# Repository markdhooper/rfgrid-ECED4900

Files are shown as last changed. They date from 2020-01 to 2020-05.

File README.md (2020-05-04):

# rfgrid - An Interactive RFID Display
Our (Mark Hooper & Burack Ozter) Senior Year Project as part of the Dalhousie Bachelor of Electrical Engineering Program.

Modular arrays of RFID readers are embedded beneath a projection surface upon which a short-throw projector displays contextual visual and audio feedback based on the application running on a host machine. 

<p align="center">
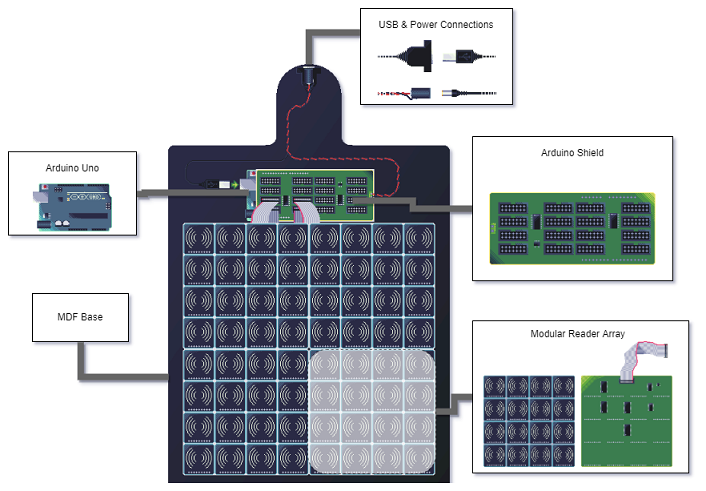
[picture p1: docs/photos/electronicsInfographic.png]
  
</p>
<p align="center">
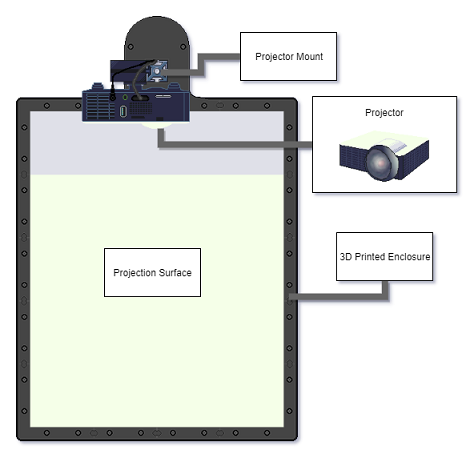
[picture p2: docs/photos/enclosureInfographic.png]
  
</p>

<p align="center">
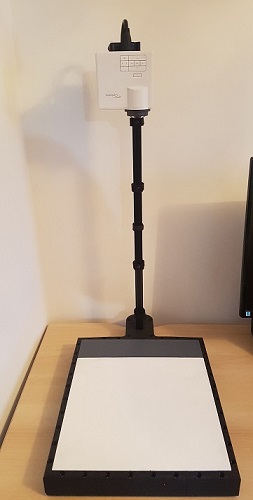
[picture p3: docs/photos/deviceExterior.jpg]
  
</p>
<p align="center">
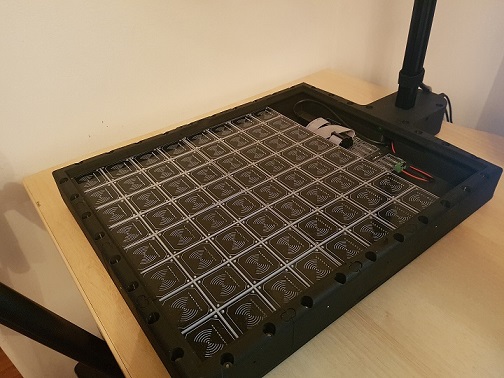
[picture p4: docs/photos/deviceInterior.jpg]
  
</p>

## Application Demonstrations
RFGRID - RPG (http://www.youtube.com/watch?v=AkpBl5bfDys)
RFGRID - SEQUENCER (http://www.youtube.com/watch?v=AWikCM2gaQc)
RFGRID - CHESS (http://www.youtube.com/watch?v=Hl0dvJiLpyY)

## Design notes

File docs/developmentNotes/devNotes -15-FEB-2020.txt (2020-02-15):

There is an issue when loading my rpg(non-communicating) game. 

I fixed the launch by renaming rfgridNOCOMM.py to rpg(non-communicating).py
I also had to comment out the include statement for the rfgridCommunication module as it was throwing because I didn't have the 
serial.tools included or something..

Also: 

I can't modify the background, or the grid on a game that already exists because it's looking for /application/8x8. This 
is a bug in where the directory is. My problem was that the config file was messed up for my game. So I ended up having to
run the calibration tool using the python script instead of the .exe. That seemed to get it working. 

Anyway, just thought i'd document this here.

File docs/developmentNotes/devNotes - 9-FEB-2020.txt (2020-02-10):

[folders]
<whatever the user named their game>

Directory Structure Requirements:
	[<gameName>]
	->[configs]
	....->grid.rfgrid          (created by running rfgridDispCalib.py)
	....->default.rfgridbg	   (created by running rfgridBackgroundCalib.py *user has to pick a background image,and it needs to be renamed and copied first!)
	....->tags.rfgridtag       (created using the C# application)
	->[fonts]
	....->__init__.py
	....->UbuntuMono-Regular.ttf
	->[images]
	....->[backgrounds]
	........->__init__.py
	........-> (the background selected by the user is copied here and renamed default.jpg)
	....->[objects]
	........->__init__.py
	........-> (whatever images selected by the user for tags are copied here)
	->[sounds]
	....-> (whatever sounds selected by the user are copied here)
	->__init__.py
	->ptext.py
	-><gameName>.py (This will be a re-named copy of rfgridGame.py (which is a modified version of the current rfgridAppTest.py))
	->rfgrid.py
	->rfgridBackgroundCalib.py
	->rfgridDispCalib.py
	->rfgridCommunications.py (I need to make this)
	->rfgridDispCalib.py

shit I need to do:
	make rfgridCommunications.py
	make rfgridGame.py (which uses rfgridCommunications.py to talk to the arduino)
	change how rfgridBackgroundCalib.py creates and stores background data (should be based on number of squares)
	change how rfgrid.py loads background information (should resize based on number of squares in default.rfgridbg)
	change the default ptext font to UbuntoMono-Regular.ttf

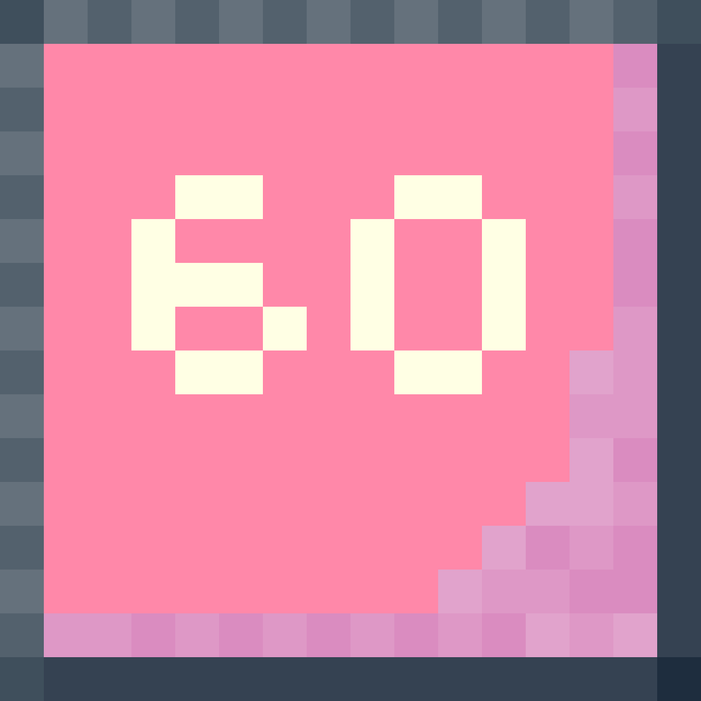
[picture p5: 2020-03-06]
applications/sequencer/images/objects/bpm60.png

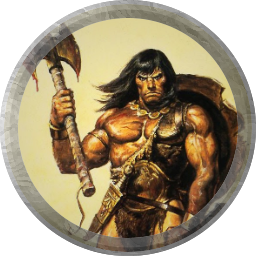
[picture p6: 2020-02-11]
applications/rpg_non_communicating/images/objects/barbarian.png

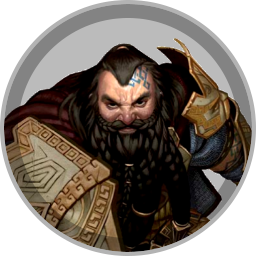
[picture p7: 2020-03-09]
applications/RPG/images/objects/dwarf.png

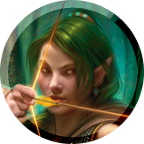
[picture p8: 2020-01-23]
applications/rpg_non_communicating/images/objects/archer.png

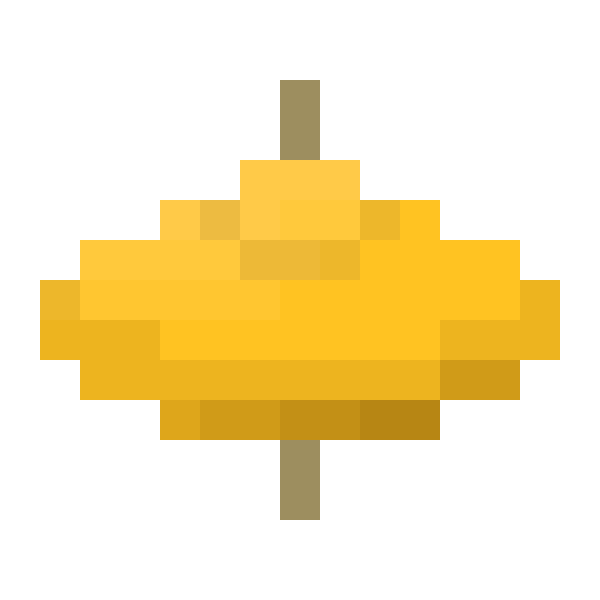
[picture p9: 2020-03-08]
applications/sequencer/images/objects/chh2.png

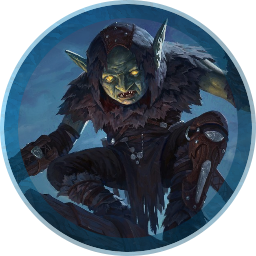
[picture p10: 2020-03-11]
applications/RPG/images/objects/e4.png

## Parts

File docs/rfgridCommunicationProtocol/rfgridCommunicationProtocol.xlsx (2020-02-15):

RFGRID - Communication Protocol
Argument Size Reference
1 Byte | 2 Bytes |  | 4 Bytes |  |  |  | Variable
H/L | H | L | HH | HL | LH | LL | MSB | … | LSB
Host - Data Transmission Format
Name | Type | CMD | Arguments/Data
UPDATE | Acknowledge | 0xF0 | ID | X | Y
GETID | Request | 0xF1 | X | Y
GETXY | Request | 0xF2 | ID
BLOCK | Request | 0xF3 | ID | ARG
READ_ID | Request | 0xF4 | ID | OFFSET | SIZE
WRITE_ID | Request | 0xF5 | ID | OFFSET | SIZE | DATA
READ_XY | Request | 0xF6 | X | Y | OFFSET | SIZE
SYNC | Request | 0xFF | START/STOP | XMAX | YMAX
Device - Data Transmission Format
Name | Type | CMD | Arguments/Data
UPDATE | Event | 0x00 | ID | X | Y
GETID | Response | 0x01 | ID | X | Y
GETXY | Response | 0x02 | ID | X | Y
BLOCK | Response | 0x03 | ID | ARG
READ_ID | Response | 0x04 | ID | OFFSET | SIZE | DATA
WRITE_ID | Response | 0x05 | ID | OFFSET | SIZE
READ_XY | Response | 0x06 | ID | X | Y | OFFSET | SIZE | DATA
SYNC | Response | 0x0F | START/STOP | XMAX | YMAX

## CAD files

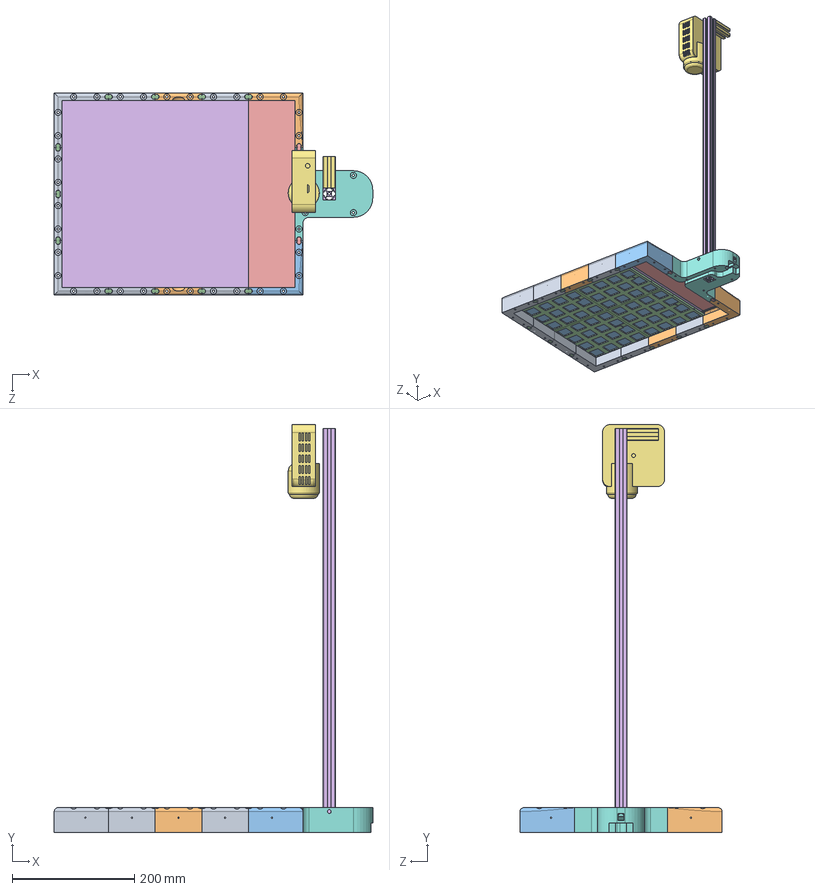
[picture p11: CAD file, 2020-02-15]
docs/cadModels/SolidWorks/rfgrid_assembly.SLDASM
520.7 x 666.8 x 330.2 mm
corner_a x 2
corner_b_l
corner_b_r
dovetail_key x 11
dovetail_key_flat x 2
extruded_aluminium_a
extruded_aluminium_b
projector_mount_base
side x 6
side_notch x 2
reader x 64
reader_tray x 4
menu_surface
projection_surface
projector

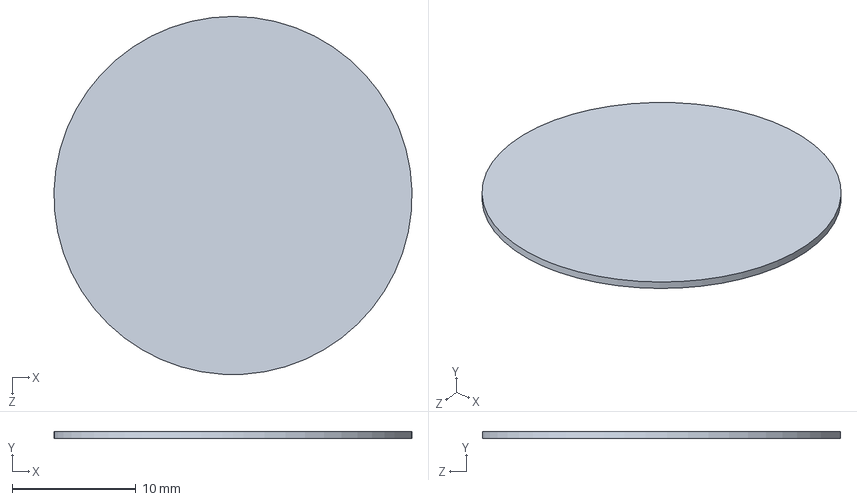
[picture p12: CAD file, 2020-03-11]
docs/cadModels/SolidWorks/cubeSpacer.SLDPRT
29.0 x 0.6 x 29.0 mm

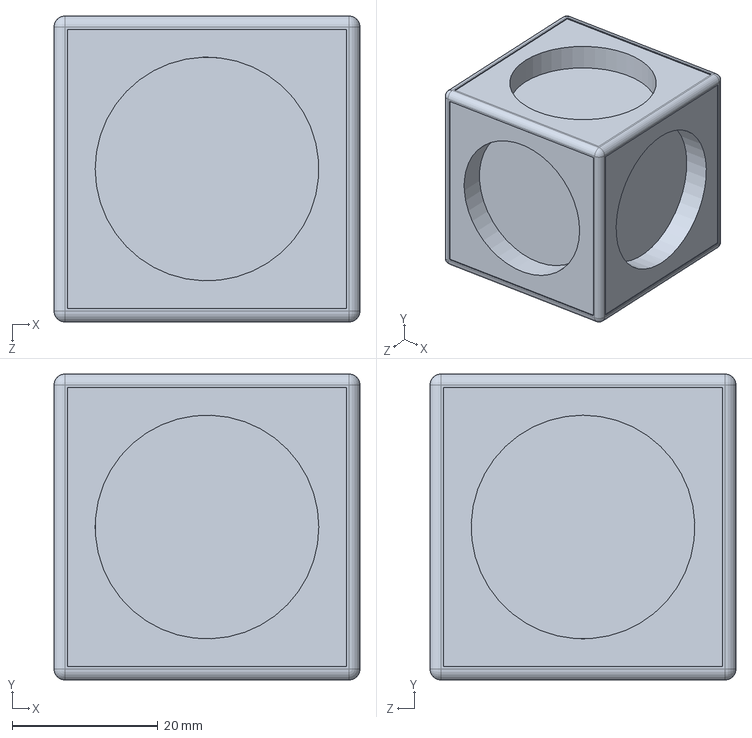
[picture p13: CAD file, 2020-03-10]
docs/cadModels/SolidWorks/tag_cube.SLDPRT
42.0 x 42.0 x 42.0 mm

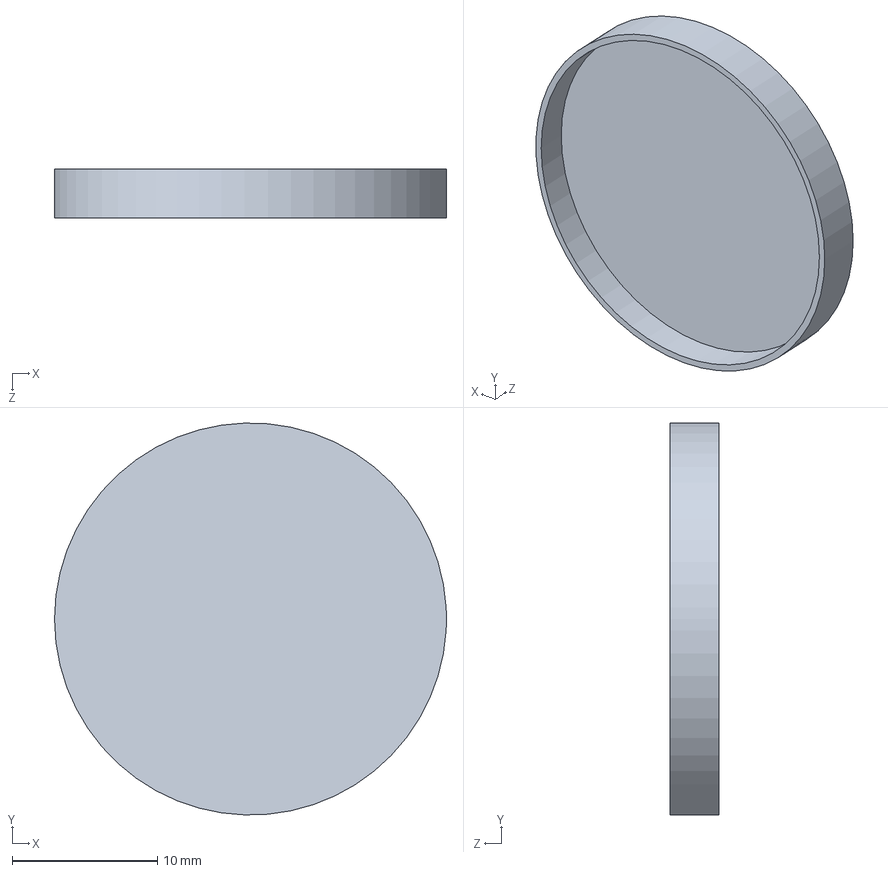
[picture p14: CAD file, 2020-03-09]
docs/cadModels/SolidWorks/rfid_tag_cover_v2(b).SLDPRT
27.0 x 27.0 x 3.40 mm

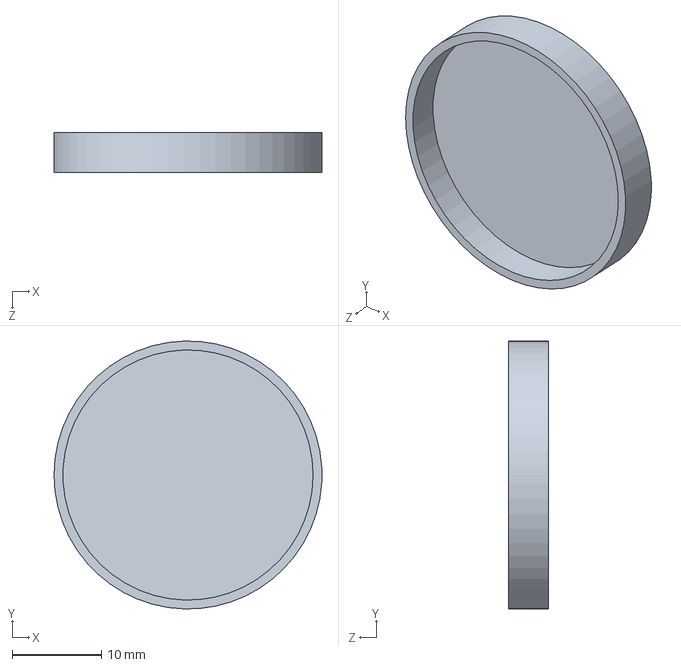
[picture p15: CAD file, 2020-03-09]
docs/cadModels/SolidWorks/rfid_tag_cover_v2(a).SLDPRT
30.0 x 30.0 x 4.50 mm

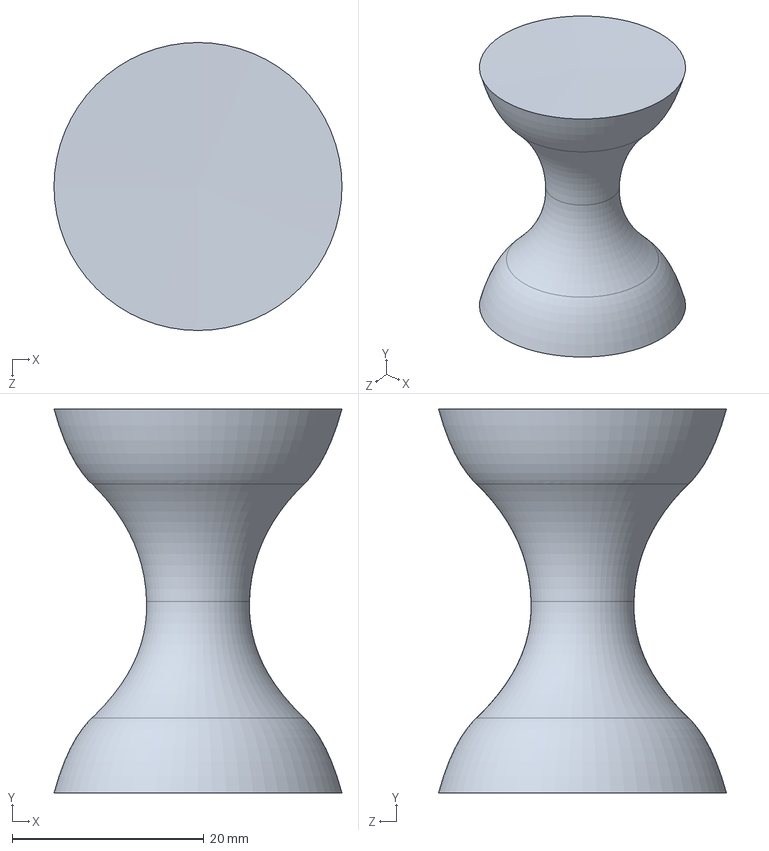
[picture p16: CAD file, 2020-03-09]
docs/cadModels/SolidWorks/turn_timer.SLDPRT
30.0 x 40.0 x 30.0 mm

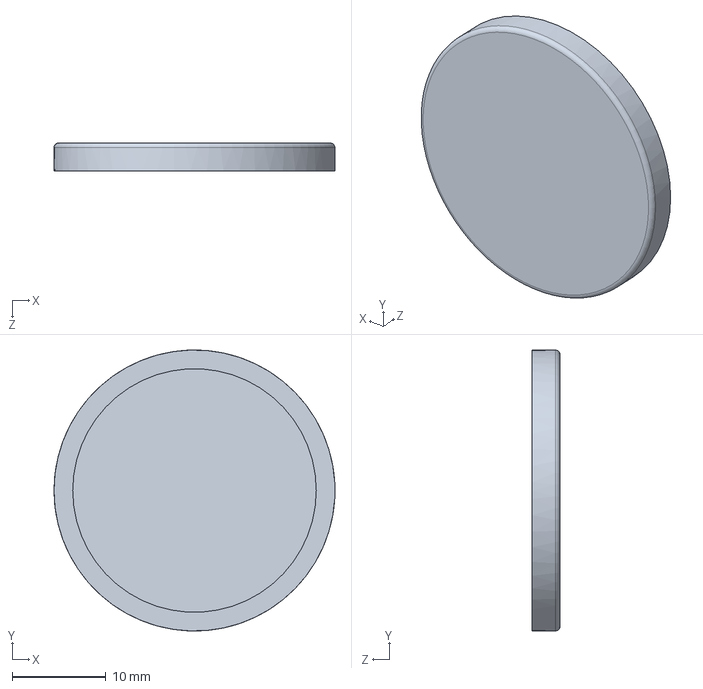
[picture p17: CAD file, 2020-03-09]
docs/cadModels/SolidWorks/rfid_tag_cover.SLDPRT
30.0 x 30.0 x 3.00 mm

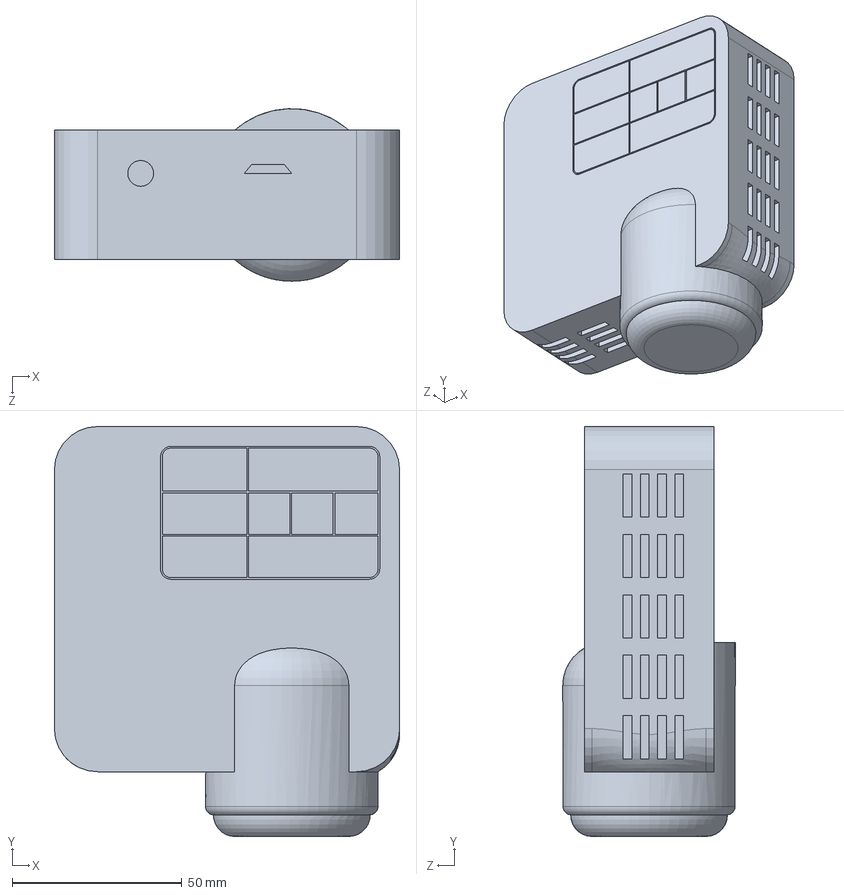
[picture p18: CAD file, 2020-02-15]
docs/cadModels/SolidWorks/projector.SLDPRT
101.6 x 120.6 x 50.8 mm

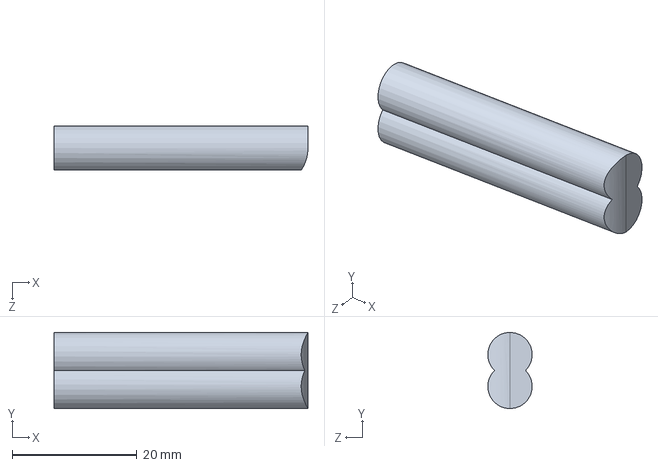
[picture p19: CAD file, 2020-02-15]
docs/cadModels/SolidWorks/dovetail_key.SLDPRT
40.6 x 12.2 x 7.10 mm

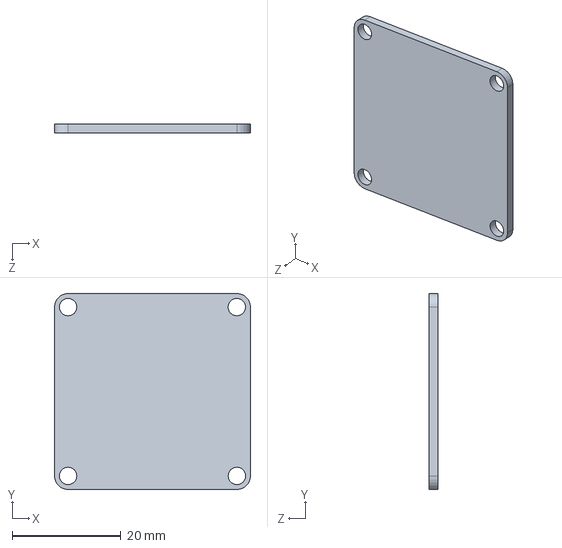
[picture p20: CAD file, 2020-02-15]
docs/cadModels/SolidWorks/reader.SLDPRT
36.0 x 36.0 x 1.60 mm

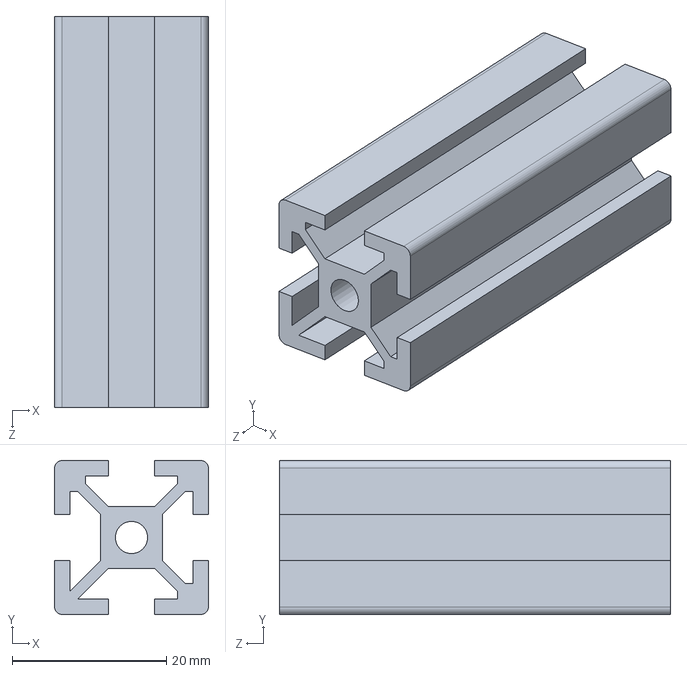
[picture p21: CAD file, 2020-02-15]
docs/cadModels/SolidWorks/extruded_aluminium_b.SLDPRT
20.0 x 20.0 x 50.8 mm

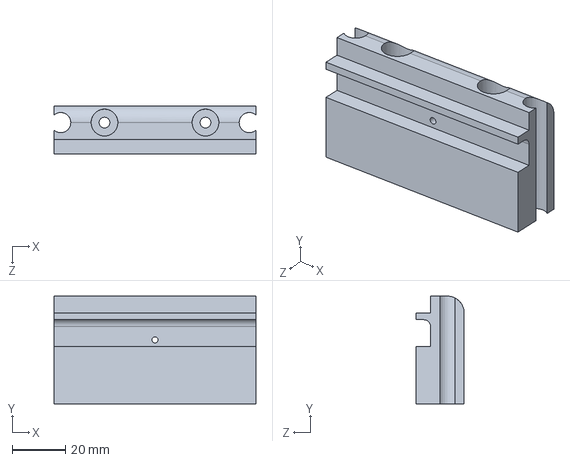
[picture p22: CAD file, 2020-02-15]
docs/cadModels/SolidWorks/side.SLDPRT
76.2 x 40.6 x 18.3 mm

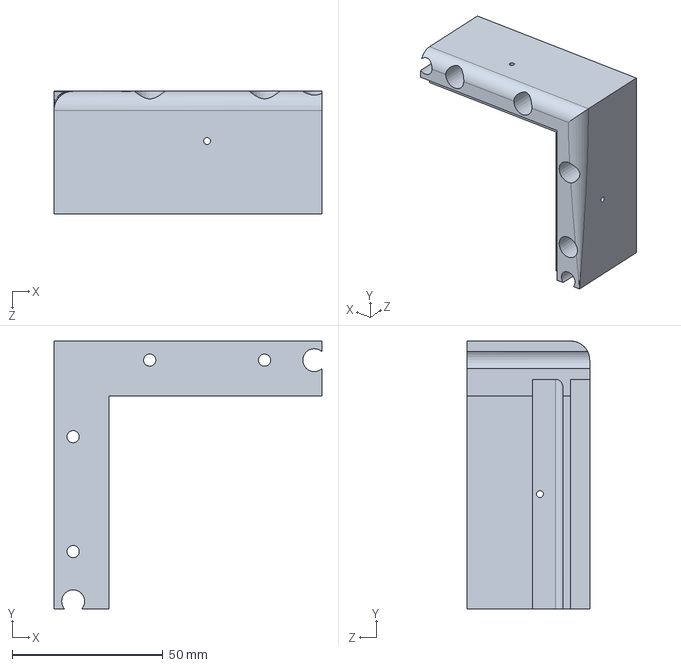
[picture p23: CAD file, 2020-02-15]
docs/cadModels/SolidWorks/corner_b_l.SLDPRT
88.9 x 88.9 x 40.6 mm

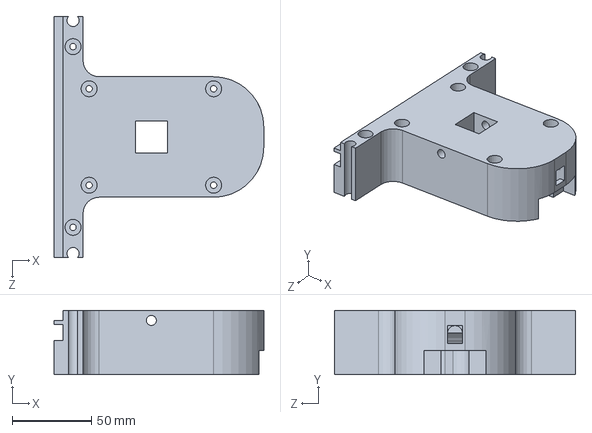
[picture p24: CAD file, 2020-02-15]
docs/cadModels/SolidWorks/projector_mount_base.SLDPRT
132.6 x 40.6 x 152.4 mm

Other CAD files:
docs/cadModels/SolidWorks/dovetail_key_flat.SLDPRT
docs/cadModels/SolidWorks/corner_b_r.SLDPRT
docs/cadModels/SolidWorks/corner_a.SLDPRT
docs/cadModels/SolidWorks/projection_surface.SLDPRT
docs/cadModels/SolidWorks/extruded_aluminium_a.SLDPRT
docs/cadModels/SolidWorks/menu_surface.SLDPRT
docs/cadModels/SolidWorks/nut_driver.SLDPRT
docs/cadModels/SolidWorks/reader_tray.SLDPRT
docs/cadModels/SolidWorks/side_notch.SLDPRT
docs/cadModels/SolidWorks/t_nut.SLDPRT
docs/cadModels/stl/corner_a.STL
docs/cadModels/stl/corner_b_l.STL
docs/cadModels/stl/corner_b_r.STL
docs/cadModels/stl/cubeSpacer.STL
docs/cadModels/stl/dovetail_key.STL
docs/cadModels/stl/dovetail_key_flat.STL
docs/cadModels/stl/nut_driver.STL
docs/cadModels/stl/projector_mount_base.STL
docs/cadModels/stl/rfid_tag_cover.STL
docs/cadModels/stl/rfid_tag_cover_v2(a).STL
docs/cadModels/stl/rfid_tag_cover_v2(b).STL
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

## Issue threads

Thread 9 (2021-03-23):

Model of board for MFRC522

dannygrob, 2021-03-23:
Hi!

Really cool project you guys made. I'm looking into making a grid of rfid readers. I can't seem to find the square MFRC522 module that you are using, can you tell me where you got those?

Are the schematics also available in gerber btw? I have no issues designing my own pcb, but having a good reference helps!

Danny

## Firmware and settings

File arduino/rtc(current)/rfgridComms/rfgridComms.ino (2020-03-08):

/*****************************************************************************/
/* Program Name:  rfgrid.ino  (https://github.com/markdhooper/rfgridECED4900)*/
/* Programmer:    Mark Hooper (https://github.com/markdhooper)               */
/* Description:   This program is intended for use with an Arduino UNO       */
/*                microcontroller connected via usb to a host machine        */
/*                running a python script at the repository linked above.    */
/*                You will also require an rfgridShield and at least one     */
/*                rfgrid modular array unit. For more information, please    */
/*                see the github repo linked above.                          */
/* Behavior:      This sketch will determine how many readers are connected. */
/*                and will inform the host machine when it detects an rfid   */
/*                tag. The current protocol is only 1-way at present.        */
/*****************************************************************************/

#include <SPI.h>
#include <MFRC522.h> //https://github.com/miguelbalboa/rfid

/*****************************************************************************/
/* Constants */
/*****************************************************************************/

/* Pin Assignments */
#define S0_PIN 2    
#define S1_PIN 3    
#define S2_PIN 4    
#define S3_PIN 5    
#define S4_PIN 6    
#define S5_PIN 7    
#define S6_PIN 8    
#define S7_PIN 9    
#define SDA_PIN 10  
#define SCK_PIN 13  
#define MOSI_PIN 11 
#define MISO_PIN 12 
#define RST_PIN 14  
#define NOT_EN_PIN 6

/* Additional Constants */
#define UPDATE_MSG_SZ 7
#define TRIAL_THRESHOLD 1
#define READER_LIMIT 256
#define BANK_MAX 16
#define READER_MAX 16
#define BLOCKED_TAG_MAX 16
#define BOARD_CONFIG4x4   0b0000000000000001
#define BOARD_CONFIG8x8   0b0000000000110011
#define BOARD_CONFIG12x12 0b0000011101110111
#define BOARD_CONFIG16x16 0b1111111111111111

/*****************************************************************************/
/* Data Structures */
/*****************************************************************************/
union readerLocation {
    uint8_t addr8;
    struct BR
	{
        uint8_t readerID : 4;
        uint8_t bankID : 4;
    }addr4;
    struct ydxdymxm
	{
        uint8_t xmod : 2;
        uint8_t ymod : 2;
        uint8_t xdiv : 2;
        uint8_t ydiv : 2;
    }xy;
  struct ab
  {
    uint8_t ar0 : 1;
    uint8_t ar1 : 1;
    uint8_t ar2 : 1;
    uint8_t ar3 : 1;
    uint8_t ab0 : 1;
    uint8_t ab1 : 1;
    uint8_t ab2 : 1;
    uint8_t ab3 : 1;
  }addrBit;
};

union intUID 
{
  byte uidArr[4];
  uint32_t UID;
};

struct flg
{
	uint8_t ACK : 1;
	uint8_t BLOCK : 1;
	uint8_t reserved : 6;
};


struct Tile
{
  uint32_t UID;
  struct flg FLAGS;
};



/*****************************************************************************/
/* Communication Protocol Defines */
/*****************************************************************************/
#define RX_UPDATE_BYTES 6       //x,y,id
#define RX_GET_ID_BYTES 2       //x,y
#define RX_GET_XY_BYTES 4       //id
#define RX_BLOCK_BYTES 5        //arg, id
#define RX_READ_ID_BYTES 8      //id, offset, size
#define RX_WRITE_ID_BYTES 8     // id, offset, size (DATA)
#define RX_READ_XY_BYTES 6      // x, y, offset, size
#define RX_SYNC_BYTES 3         // begin, xmax, ymax

#define TX_UPDATE_BYTES 7       // CMD, x,y,id
#define TX_GET_ID_BYTES 7       // CMD, x,y,id
#define TX_GET_XY_BYTES 7       // CMD, x,y,id
#define TX_BLOCK_BYTES 6        // CMD, arg, id
#define TX_READ_ID_BYTES 9      // CMD, id, offset, size, (DATA)
#define TX_WRITE_ID_BYTES 9     // CMD, id, offset, size
#define TX_READ_XY_BYTES 11      // CMD, x, y, id, offset, size (DATA)
#define TX_SYNC_BYTES 4         // CMD, begin, x_max, y_max

/*****************************************************************************/
/* Global Variables */
/*****************************************************************************/
union intUID objID;
struct Tile Tiles[READER_LIMIT];
MFRC522 Reader(SDA_PIN, RST_PIN);
int ReaderCount = 0;
uint16_t boardMask = 0xFFFF;
uint8_t boardSequence[16] = {0,0,0,0,0,0,0,0,0,0,0,0,0,0,0,0};
uint8_t boardSeqLen = 0;
uint32_t blockedTags[BLOCKED_TAG_MAX];
int BLOCKS_IN_EFFECT = 0;
bool SYNC = 0;
uint8_t x_max_global = 0;
uint8_t y_max_global = 0;


/*****************************************************************************/
/* These automatically get called based on the CMD byte read in the loop()   */
/*****************************************************************************/
void RX_UPDATE()
{
	uint8_t x, y;
	intUID rx_id;
	
	byte argBytes[RX_UPDATE_BYTES];
	Serial.readBytes(argBytes,RX_UPDATE_BYTES);
	
	x = argBytes[4]; 
	y = argBytes[5]; 
	rx_id.uidArr[0] = argBytes[3];
	rx_id.uidArr[1] = argBytes[2]; 
	rx_id.uidArr[2] = argBytes[1]; 
	rx_id.uidArr[3] = argBytes[0]; 
	
	//host has acknowledged an update sent by the device
	//clear the ACK flag for the corresponding reader
	uint8_t addr;
	XYToAddr(x,y,addr);
	if(Tiles[addr].UID == rx_id.UID)
	{
		Tiles[addr].FLAGS.ACK = 0;
	}

}

void RX_GET_ID()
{
	uint8_t x, y;
	uint32_t id;
	
	byte argBytes[RX_GET_ID_BYTES];
	Serial.readBytes(argBytes,RX_GET_ID_BYTES);
	
	x = argBytes[0];
	y = argBytes[1];
	
	uint8_t addr;
	XYToAddr(x,y,addr);
	id = Tiles[addr].UID;
	
	//transmit the result
	TX_GET_ID(id, x, y);
  
}

void RX_GET_XY()
{
	uint8_t x = 255; 
	uint8_t y = 255;
	intUID id;
	
	byte argBytes[RX_GET_XY_BYTES];
	Serial.readBytes(argBytes,RX_UPDATE_BYTES);
	
	id.uidArr[0] = argBytes[3];
	id.uidArr[1] = argBytes[2];
	id.uidArr[2] = argBytes[1];
	id.uidArr[3] = argBytes[0];
       
	union readerLocation addr;
	for(int i = 0; i < boardSeqLen; i++)
	{
		addr.addr4.bankID = boardSequence[i];
		for(int j = 0; j < 16; j++)
		{
			addr.addr4.readerID = (uint8_t)j;
			
			if(Tiles[addr.addr8].UID == id.UID)
			{
				addrToXY(addr.addr8,x,y);
			}
		}
	}
	
	//transmit the result
	TX_GET_XY(id.UID,x,y);
}

void RX_BLOCK()
{
	uint8_t arg;
	intUID id;
  
	byte argBytes[RX_BLOCK_BYTES];
	Serial.readBytes(argBytes,RX_BLOCK_BYTES);  

    id.uidArr[0] = argBytes[3];
    id.uidArr[1] = argBytes[2];
    id.uidArr[2] = argBytes[1];
    id.uidArr[3] = argBytes[0];
    arg = argBytes[4];

  if(id.UID == 0){
    arg = 0;
    TX_BLOCK(id.UID,arg);
    return;
  }
  
  if(arg)
  {
	  //host wants us to block updates from this UID
	  for(int i = 0; i < BLOCKED_TAG_MAX; i++)
	  {
		  if(!blockedTags[i])
		  {
			  //we found a free slot, store the ID of the tag to block
			  blockedTags[i] = id.UID;
			  BLOCKS_IN_EFFECT++;
        for(int j = 0; j< READER_LIMIT; j++)
        {
          if(Tiles[j].UID == id.UID)
          {
            Tiles[j].FLAGS.BLOCK = 1;
            Tiles[j].FLAGS.ACK = 0;
            break;  
          }
        }
        break;
		  }
		  else if(i == BLOCKED_TAG_MAX -1)
		  {
			  //We can't block this tag until they unblock another one
			  arg = 0;
		  }
	  }
  }
  else
  {
	  //they want to unblock a tag
	  for(int i = 0; i < BLOCKED_TAG_MAX; i++)
	  {
		  if(blockedTags[i] == id.UID)
		  {
			  //we found a match
			  blockedTags[i] = 0;
			  BLOCKS_IN_EFFECT--;
        //Search for a reader with an id that matches our blocked tag
        // and clear the flag
        for(int j = 0; j< READER_LIMIT; j++)
        {
          if(Tiles[j].UID == id.UID)
          {
            //we found a match, unblock 
            //the reader. And ensure that
            //it tells the host where the
            //newely unblocked tag is.
            Tiles[j].FLAGS.BLOCK = 0;
            Tiles[j].FLAGS.ACK = 1;
            break;  
          }
        }
        break;
		  }
	  }
  }

  //transmit the result
  TX_BLOCK(id.UID,arg);
}

void RX_READ_ID()
{
  intUID id;
  uint16_t ofs;
  uint16_t sz;
  byte data[16];    //FIXED SIZES WILL BE NEEDED, WE CAN PICK A MAXIMUM (FOR NOW) OF 16
  
  byte argBytes[RX_READ_ID_BYTES];
  Serial.readBytes(argBytes,RX_UPDATE_BYTES);

  //do the things

  /*****************************************************************************/
  /* HARD CODED - ONLY FOR TESTING, THE REAL VALUES WILL NEED TO BE COMPUTED   */
              id.uidArr[0] = argBytes[3];
              id.uidArr[1] = argBytes[2];
              id.uidArr[2] = argBytes[1];
              id.uidArr[3] = argBytes[0];
              ofs = argBytes[4] + (argBytes[5]<<8);
              sz = 16;  //going with a fixed size for now....
  /*****************************************************************************/

  //transmit the result
  TX_READ_ID(id.UID, ofs, sz, data);
}

void RX_WRITE_ID()
{
  intUID id;
  uint16_t ofs;
  uint16_t sz;
  
  byte argBytes[RX_WRITE_ID_BYTES];
  Serial.readBytes(argBytes,RX_UPDATE_BYTES);

  //do the things

  /*****************************************************************************/
  /* HARD CODED - ONLY FOR TESTING, THE REAL VALUES WILL NEED TO BE COMPUTED   */
              id.uidArr[0] = argBytes[3];
              id.uidArr[1] = argBytes[2];
              id.uidArr[2] = argBytes[1];
              id.uidArr[3] = argBytes[0];
              ofs = argBytes[5] + (argBytes[4]<<8);
              sz = argBytes[7] + (argBytes[6]<<8);
  /*****************************************************************************/

  //transmit the result
  TX_WRITE_ID(id.UID, ofs, sz);
}

void RX_READ_XY()
{
  uint8_t x;
  uint8_t y;
  uint32_t id;
  uint16_t ofs;
  uint16_t sz;
  
  byte argBytes[RX_READ_XY_BYTES];
  Serial.readBytes(argBytes,RX_UPDATE_BYTES);  

  //do the things


  /**********************************************************************/
  /* HARDCODED ONLY FOR TESTING, these values will need to be computed  */
          x = argBytes[0];
          y = argBytes[1];
          id = 0xBEEF;
          ofs = (argBytes[2]<<8) + argBytes[3];
          sz = (argBytes[4]<<8) + argBytes[5];
          byte data[sz];
  /**********************************************************************/
  
  //transmit the result
  TX_READ_XY(x, y, id, ofs, sz, data);
}

void RX_SYNC()
{
	uint8_t arg;
	uint8_t x_max;
	uint8_t y_max;
	
	byte argBytes[RX_SYNC_BYTES];
	Serial.readBytes(argBytes,RX_SYNC_BYTES);
	

	arg = argBytes[0];
  x_max = argBytes[1];
  y_max = argBytes[2];
  
	if(!arg){
		//host wants to stop communicating
		SYNC = false;
	}else if(x_max_global == x_max && y_max_global == y_max){
    SYNC = true;
	}else{
	  arg = 0;
    x_max = x_max_global;
    y_max = y_max_global;
	}
	
	//transmit the result
	TX_SYNC(arg,x_max,y_max);
}


/*****************************************************************************/
/* Call these when you want to transmit a specific response to the Host      */
/*****************************************************************************/

void TX_UPDATE(uint32_t id, uint8_t x, uint8_t y )
{
    intUID temp;
    temp.UID = id;
    uint8_t buf[TX_UPDATE_BYTES];
    buf[0] = 0x00;        //UPDATE COMMAND
    buf[1] = temp.uidArr[3];
    buf[2] = temp.uidArr[2];
    buf[3] = temp.uidArr[1];
    buf[4] = temp.uidArr[0];
    buf[5] =  x;
    buf[6] =  y;
    Serial.write(buf, TX_UPDATE_BYTES);
}

void TX_GET_ID(uint32_t id, uint8_t x, uint8_t y)
{
    intUID temp;
    temp.UID = id;
    uint8_t buf[TX_GET_ID_BYTES];
    buf[0] = 0x01;        //GET_ID COMMAND
    buf[1] = temp.uidArr[3];
    buf[2] = temp.uidArr[2];
    buf[3] = temp.uidArr[1];
    buf[4] = temp.uidArr[0];
    buf[5] =  x;
    buf[6] =  y;
    Serial.write(buf, TX_GET_ID_BYTES);
}

void TX_GET_XY(uint32_t id, uint8_t x, uint8_t y)
{
    intUID temp;
    temp.UID = id;
    uint8_t buf[TX_GET_XY_BYTES];
    buf[0] = 0x02;        //GET_XY COMMAND
    buf[1] = temp.uidArr[3];
    buf[2] = temp.uidArr[2];
    buf[3] = temp.uidArr[1];
    buf[4] = temp.uidArr[0];
    buf[5] =  x;
    buf[6] =  y;
    Serial.write(buf, TX_GET_XY_BYTES);
}

void TX_BLOCK(uint32_t id, uint8_t arg)
{
    intUID temp;
    temp.UID = id;
    uint8_t buf[TX_BLOCK_BYTES];
    buf[0] = 0x03;        //BLOCK COMMAND
    buf[1] = temp.uidArr[3];
    buf[2] = temp.uidArr[2];
    buf[3] = temp.uidArr[1];
    buf[4] = temp.uidArr[0];
    buf[5] =  arg;
    Serial.write(buf, TX_BLOCK_BYTES);
}

void TX_READ_ID(uint32_t id, uint16_t ofs, uint16_t sz, byte* data)
{
    intUID temp;
    temp.UID = id;
    uint8_t buf[TX_READ_ID_BYTES + sz];
    buf[0] = 0x04;        //READ_ID COMMAND
    buf[1] = temp.uidArr[3];
    buf[2] = temp.uidArr[2];
    buf[3] = temp.uidArr[1];
    buf[4] = temp.uidArr[0];
    buf[5] = (ofs & 0xFF00)>>8;
    buf[6] = (ofs & 0x00FF);
    buf[7] = (sz & 0xFF00)>>8;
    buf[8] = (sz & 0x00FF);
    for(int i = 0; i < sz; i++)
    {
      buf[i+8] = *data;
      data++; 
    }
    Serial.write(buf, TX_READ_ID_BYTES + sz);
}

void TX_WRITE_ID(uint32_t id, uint16_t ofs, uint16_t sz)
{
    intUID temp;
    temp.UID = id;
    uint8_t buf[TX_READ_XY_BYTES];
    buf[0] = 0x05;        //WRITE_ID COMMAND
    buf[1] = temp.uidArr[3];
    buf[2] = temp.uidArr[2];
    buf[3] = temp.uidArr[1];
    buf[4] = temp.uidArr[0];
    buf[5] = (ofs & 0xFF00)>>8;
    buf[6] = (ofs & 0x00FF);
    buf[7] = (sz & 0xFF00)>>8;
    buf[8] = (sz & 0x00FF);
    Serial.write(buf, TX_WRITE_ID_BYTES + sz);
}

void TX_READ_XY(uint8_t x, uint8_t y,uint32_t id, uint16_t ofs, uint16_t sz, byte* data)
{
    intUID temp;
    temp.UID = id;
    uint8_t buf[TX_READ_XY_BYTES + sz];
    buf[0] = 0x06;        //READ_XY COMMAND
    buf[1] = x;
    buf[2] = y;
    buf[3] = temp.uidArr[3];
    buf[4] = temp.uidArr[2];
    buf[5] = temp.uidArr[1];
    buf[6] = temp.uidArr[0];
    buf[7] = (ofs & 0xFF00)>>8;
    buf[8] = (ofs & 0x00FF);
    buf[9] = (sz & 0xFF00)>>8;
    buf[10] = (sz & 0x00FF);
    for(int i = 0; i < sz; i++)
    {
      buf[i+10] = *data;
      data++; 
    }
    Serial.write(buf, TX_READ_XY_BYTES + sz);
}

void TX_SYNC(uint8_t arg, uint8_t x_max, uint8_t y_max)
{
  uint8_t buf[TX_SYNC_BYTES] = {0x0F, arg, x_max, y_max};
  Serial.write(buf, TX_SYNC_BYTES);
}


/*****************************************************************************/
/* Lookup table: the CMD is bitwise anded with 0x07 which gives the index of */
/* the function to call                                                      */
/*****************************************************************************/
void (*RX_LUT[])() = 
{
  RX_UPDATE,
  RX_GET_ID,
  RX_GET_XY,
  RX_BLOCK,
  RX_READ_ID,
  RX_WRITE_ID,
  RX_READ_XY,
  RX_SYNC
}; 


/*****************************************************************************/
/* Functions: (SPI communication, and address translation) */
/*****************************************************************************/

/* Output an 8-bit address to the SPI MUX */
void outputAddress(uint8_t addr)
{
  union readerLocation readerAddr;
  readerAddr.addr8 = addr;
  digitalWrite(S0_PIN, readerAddr.addrBit.ar0);
  digitalWrite(S1_PIN, readerAddr.addrBit.ar1);
  digitalWrite(S2_PIN, readerAddr.addrBit.ar2);
  digitalWrite(S3_PIN, readerAddr.addrBit.ar3);
  digitalWrite(S4_PIN, readerAddr.addrBit.ab0);
  digitalWrite(S5_PIN, readerAddr.addrBit.ab1);
  digitalWrite(S6_PIN, readerAddr.addrBit.ab2);
  digitalWrite(S7_PIN, readerAddr.addrBit.ab3);
}

/* Tests if a reader is present at a given address */
bool initReader(uint8_t addr)
{
  bool result;
  outputAddress(addr);
  delay(10);
  Reader.PCD_Init();
  int numTrials = 0;
  int gainTest = 16;
  for(int j = 0; j < TRIAL_THRESHOLD; j++)
  {
    Reader.PCD_SetAntennaGain(gainTest);
    if(Reader.PCD_GetAntennaGain() == gainTest)
	{
      numTrials++;
    }
  }
  Reader.PCD_AntennaOff();  
  return (numTrials == TRIAL_THRESHOLD);
}
/*****************************************************************************/
//                                                                                       DELETE LATER
/*  */
void sendUpdate(uint8_t addr, uint32_t ID)
{
  union intUID tagID;
  tagID.UID = ID;
  uint8_t msg[UPDATE_MSG_SZ];
  msg[0] = 0;
  msg[1] = tagID.uidArr[3];
  msg[2] = tagID.uidArr[2];
  msg[3] = tagID.uidArr[1];
  msg[4] = tagID.uidArr[0];
  addrToXY(addr,msg[5],msg[6]);
  Serial.write(msg,UPDATE_MSG_SZ);
}

/* Translates an x,y coordinate to an address */
int XYToAddr(byte x, byte y, byte &addr)
{
    union readerLocation RL;
    if((x > 15) || (y > 15)) return 1;
    RL.xy.xmod = x % 4;
    RL.xy.ymod = y % 4;
    RL.xy.xdiv = x/4;
    RL.xy.ydiv = y/4;
    addr = RL.addr8;
    return 0;
}

/* Translates an address to an xy coordinate */
int addrToXY(uint8_t addr, uint8_t &x, uint8_t &y)
{
    union readerLocation RL;
    if(addr > 255) return 1;
    RL.addr8 = addr;
    x = (RL.xy.xdiv * 4) + RL.xy.xmod;
    y = (RL.xy.ydiv * 4) + RL.xy.ymod;
    return 0;    
}

/* checks to see if a given UID is blocked */
bool blocked(uint32_t UID){
	for(int i = 0; i < BLOCKED_TAG_MAX; i++)
	{
		if(blockedTags[i] == UID && UID)
		{
			return true;
		}
	}
	return false;
}
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
void loop()
{
	if(Serial.available())
	{
		byte cmd = Serial.read();
		cmd &= 0x07;      //get the proper index for the LUT
		RX_LUT[cmd]();    //Call the appropriate RX function
	}
	else if(SYNC)
	{
	//No messages from host, scan grid for updates.
		union readerLocation currentAddress;
		for(int i = 0; i < boardSeqLen; i++)
		{
			currentAddress.addr4.bankID = boardSequence[i];
			for(int j = 0; j < 16; j++)
			{
				currentAddress.addr4.readerID = (uint8_t)j;
				outputAddress(currentAddress.addr8); 
				delay(10);
				Reader.PCD_AntennaOn();
				Reader.PCD_SetAntennaGain(16);
				if(Reader.PICC_IsNewCardPresent() && Reader.PICC_ReadCardSerial())
				{
					Reader.PCD_AntennaOff();  
					for( int k = 1; k <= 4; k++)
					{
						objID.uidArr[4-k] = Reader.uid.uidByte[k-1];
					}      
					if((objID.UID != Tiles[currentAddress.addr8].UID)||Tiles[currentAddress.addr8].FLAGS.ACK)
					{
						//State change or host has yet to acknowledge previous state change
						Tiles[currentAddress.addr8].UID = objID.UID;
						if(BLOCKS_IN_EFFECT && blocked(Tiles[currentAddress.addr8].UID))
						{
							Tiles[currentAddress.addr8].FLAGS.BLOCK = 1;
						}
						else
						{
							Tiles[currentAddress.addr8].FLAGS.ACK = 0; //set the acknowledge required flag
							sendUpdate(currentAddress.addr8,Tiles[currentAddress.addr8].UID);
						}
					}
				}
				else
				{
          //No tag was detected 
					Reader.PCD_AntennaOff();
					if((Tiles[currentAddress.addr8].UID != 0))
					{
						//State change or host has yet to acknowledge previous state change
						Tiles[currentAddress.addr8].UID = 0;
            
						if(!Tiles[currentAddress.addr8].FLAGS.BLOCK)
						{
							//updates for the tag previously on this reader are not blocked by host
							Tiles[currentAddress.addr8].FLAGS.ACK = 0; //set the acknowledge required flag
							sendUpdate(currentAddress.addr8,Tiles[currentAddress.addr8].UID);
						}
						else
						{
							//updates for the tag previously on this reader were blocked
							Tiles[currentAddress.addr8].FLAGS.BLOCK = 0;
              Tiles[currentAddress.addr8].FLAGS.ACK = 0;
						}
					}
				}
			}
		}
	}
}

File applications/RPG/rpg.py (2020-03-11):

from rfgrid import *
from rfgridCommunication import *
from time import sleep

rfgrid = rfgridInit()
rfgrid.updateMenu("Initializing Grid:\nPlease Wait...",40,(0,0,0),(255,255,255))
rfgridSerial = rfgridCommInit(rfgrid.grid_x_tiles, rfgrid.grid_y_tiles)
done = False
numPlayers = 4
currentPlayer = 0
playerNames = ["Verrona","Udoghast","Lud","Rugren"]
id = 0
x = 0
y = 0

# THESE ARE SPECIFIC TO rpg.py
MUTE = 2302950640
END_TURN = 695941360
EXPLORE = 2311927792
SCROLL_OFF = 963853040 
SCROLL_ON = 2307276272
MENU_COLOR = (200,200,200)


while not done:
	if (rfgridSerial.inWaiting() > 0):
		# there is data in the serial buffer
		# extract the command byte, and the arguments from the buffer
		cmdIdx, args = rx_rfgrid(rfgridSerial)
		if cmdIdx == 7:
			rfgrid.updateMenu("rfgrid - rpg",60,(0,0,0),MENU_COLOR)
		if cmdIdx == 0:
			id, x, y = RX_LUT[RX_LUT_KEYS[cmdIdx]](args,rfgrid)
			
			# Mute all audio 
			if id == MUTE:
				pygame.mixer.fadeout(5000)
				
			# End the current turn and locate 
			elif id == END_TURN:
				if currentPlayer == numPlayers:
					rfgrid.updateMenu("Dungeon Master's Turn",40,(0,0,0),MENU_COLOR)
					currentPlayer = 0
				else:
					# inform the player that it's their turn
					msg = ("%s's Turn:" % (playerNames[currentPlayer]))
					rfgrid.updateMenu(msg,40,(0,0,0),MENU_COLOR)
					# attempt to pan the map to display that character
					rfgrid.moveCameraToTag(currentPlayer)
					currentPlayer += 1
					
			# Enable background scrolling for tags with renderable images
			elif id == SCROLL_ON:
				rfgrid.scroll_enabled = True
				MENU_COLOR = (200,200,200)
				msg = "\n Character Scrolling ENABLED"
				rfgrid.updateMenu(msg,30,(0,0,0),MENU_COLOR)
			
			# Disable background scrolling for tags with renderable images
			elif id == SCROLL_OFF:
				rfgrid.scroll_enabled = False
				MENU_COLOR = (200,100,100)
				msg = "\n Character Scrolling DISABLED"
				rfgrid.updateMenu(msg,30,(255,0,0),MENU_COLOR)
			
			elif id == EXPLORE:
				step_size = 0
				x_dir = 0
				y_dir = 0
				
				# x cases
				if(x == 0):
					step_size = 7
					x_dir = 1
				elif(x == 1):
					step_size = 2
					x_dir = 1
				elif(x == 7):
					step_size = 7
					x_dir = -1
				elif(x == 6):
					step_size = 2
					x_dir = -1
				
				# y cases
				if(y == 0):
					step_size = 7
					y_dir = 1
				elif(y == 1):
					step_size = 2
					y_dir = 1
				elif(y == 7):
					step_size = 7
					y_dir = -1
				elif(y == 6):
					step_size = 2
					y_dir = -1
						
				for i in range(0,step_size):
					rfgrid.scrollBackground(x_dir,y_dir,smooth = True, speed = 20)
		else:
			RX_LUT[RX_LUT_KEYS[cmdIdx]](args,rfgrid)

	for event in pygame.event.get():
		# IF USER CLOSES THE WINDOW
		if event.type == pygame.QUIT:
			done=True
		
		# ESCAPE KEYPRESS
		if event.type == pygame.KEYDOWN and event.key == pygame.K_ESCAPE:
			done=True

		# ARROW KEYPRESSES
		if event.type == pygame.KEYDOWN and event.key == pygame.K_RIGHT:
			rfgrid.scrollBackground(-1,0,smooth = False)
		elif event.type == pygame.KEYDOWN and event.key == pygame.K_LEFT:
			rfgrid.scrollBackground(+1,0,smooth = False)
		elif event.type == pygame.KEYDOWN and event.key == pygame.K_UP:
			rfgrid.scrollBackground(0,+1,smooth = False)
		elif event.type == pygame.KEYDOWN and event.key == pygame.K_DOWN:
			rfgrid.scrollBackground(0,-1, smooth = False)
	
	clock.tick(20)
pygame.quit()

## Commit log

2020-01-10 Mass upload of software for the rfgrid system: I've never attempted to use gitHub in its intended fashion until today. So this is my first attempt at gettings things more organized. There are current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
    arduino:
    Added the most up-to-date version of the arduino sketch that is currently running on the device.
    Note, this is not using a two way protocol, it is simply sending the x,y and ID of tags.
    python:
    rfgridTools:
    There are some tools that I wrote to make development easier and to
    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
    [rfgridConfig.txt]
2020-01-11 Updated the calibration state and program flow to be more concise and readable. Changed the scaling step to use the left click instead of right click.
2020-01-11 Added configuration file output for grid and backgrounds
    [configsc.txt]
2020-01-13 Changed the calibration to two different scripts. Started preliminary work on pygame wrapper (rfgrid.py) Changed some config file formatting to include the x and y tile count from the background imag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
    [configsc.txt]
2020-01-13 Added draw functionality for game objects, updated app to draw random squares to test. also created a new surface on which to draw game objects. started preliminary work on state table corresponding 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
2020-01-17 Made improvements to backgroud scaler. It is less reliant on cursor position now and automatically adjusts the offset into the grid ensuring that any gaps are divided among the top/bottom or left/rig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
2020-01-19 Cathy's Stuff
    Uploading a preliminary tested version of GETID with python and arduino back and forth.
2020-01-21 GetID and GetXY both tested
    [rfgridConfig.txt]
2020-01-23 Added hardware redesign documentation and work done to prepare for meeting with Dr. Hughes. (rfgridAppTest.py)
    [rfgridModuleSpecifications.xlsx]
2020-01-23 Removed the work that I did today on the hardware re-design as it doesn't pertain to this repo anymore.
    [rfgridModuleSpecifications.xlsx]
2020-01-28 Removed un-necessary print statements, extra backgrounds, un-used images and un-necessary background config files.
    Also re-ran the calibration tool and set the resolution back to 1600x900 (it was changed to 1024x768 and
    the background scaling was not working properly for larger images as a result.
    [rfgrid.py]
2020-01-31 Re-configured the backgrounds and grid calibration files for the new hardware configuration. Adjusted the rfgridAppTest.py file to test out the drawing features that I wrote yesterday now that I have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
2020-02-05 Made communication protocol testing applications for both arduino and python.
2020-02-05 Updated the Communication Protocol Testing Suite. Fixed a bug from the TX side for python. Now can transmit raw bytes.
    [rfgridCommProtocol.py, rfgridComms.ino]
2020-02-07 Re-calibrated the display and added updated communication protocol spreadsheet to the docs folder.
    [rfgridCommunicationProtocol.xlsx]
2020-02-08 Created a new arduino sketch (rfgridComms.ino) tested with rfgridCommProtocol.py. Got sync, getxy, getid, update and block working in one sitting. Works with the grid hardware.
    [rfgridConfig.txt]
2020-02-09 Updated the rfgridComms.ino sketch to fix a quirk of block for sending removal information. Also adjusted consecutive SYNC response behavior. Added missing rx block dialogue in the rfgridCommProtocol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
    [rfgridCommProtocol.py, rfgridComms.ino]
2020-02-10 Consolidated directory structure as required for the rfgrid GUI application (Burak). Arduino real time communication is working, communication emulation is working, and implemented rfgridCommunicatio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
    [CORNER(V2).SLDPRT, CORNER(V2).STL, CORNER-PMOUNT-L(V2).SLDPRT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]
2020-02-10 Uploaded PCB Schematics and re-organized documentation folders.
2020-02-15 Added VS Code and BackgroundCalib fixed
    [rfgrid.py, rfgridCommunication.py]
2020-02-15 Re-organized the documentation folder, renamed the files for the CAD models to make more sense. Updated the communication protocol emulator to auto detect the com port for an arduino.
    [CORNER(V2).SLDPRT, CORNER-PMOUNT-L(V2).SLDPRT, CORNER-PMOUNT-R(V2).SLDPRT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]
2020-02-18 Made a (non-communicating) version of chess, and also fixed a sound bug for all rfgrid.py files, we ensure that the number of channels is set to the number of tags in the tags.rfgridtag file.
    [rfgrid.py, rfgridCommunication.py]
2020-02-18 Fixed tag scanning feature in RFGRID GUI, fixed sound playpack in rfgrid.py, updated and scanned in chess.
    [miniterm.py, rfgrid.py, rfgridCommunication.py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]
2020-03-06 Created assets for a sampler/sequencer application. Re-encoded .wav files (Roland 808 drum sounds) for use with pygame (16 bit signed wav). Still need to program the actual application as it is unlik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
2020-03-06 Updated sampler.py, can now draw non-tag objects in a modified rfgrid.draw() to illuminate the sampler buttons.
2020-03-07 Created new grphics for the sequencer. Added play/pause functionality. Added the ability to adjust the BPM and Volume. Modified the tag files to use different samples for the drum sounds.
2020-03-08 Modified the Arduino code to pre-aknowledge all update messages in order to speed up the sequencer updates. Also modified the way in which object surfaces are rendered within draw as the loading and 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
2020-03-09 Added turn sequences, mute, and movement specific tags to rpg.py. Updated rpg assets including enemy tokens, hero tokens, sounds etc. Also added solid works files for tag covers and a sand timer piec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
    [rfid_tag_cover.SLDPRT, rfid_tag_cover.STL, rfid_tag_cover_v2(a).SLDPRT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]
2020-03-09 Cleaned up the docs folder, added images for use with the RPG in labelling the physical tags. Added CAD files for a "tag cube", a printable cube that can accomodate 6 tags, with recessed sections for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
    [rfid_tag_cover.SLDPRT, rfid_tag_cover.STL, rfid_tag_cover_v2(a).STL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]
2020-03-09 Cleaned up the applications folder, and deleted some directories that are no longer required.
    [rfgrid.py, rfgridCommunication.py]
2020-03-10 Adjusted the tag_cube tolerances and created scroll enable/disable logos for the cube stickers.
    [tag_cube.SLDPRT, tag_cube.STL]
2020-03-10 Changed the python-3.7.6 folder in order to resolve an issue with the new executable.
    [rfid_tag_cover.SLDPRT, rfid_tag_cover.STL]
2020-03-11 Added in the tag entries for both cubes used in the rpg, also added the ability to enable/disable character scrolling. Also removed some other files that were no longer needed.
    [cubeSpacer.SLDPRT, cubeSpacer.STL]
